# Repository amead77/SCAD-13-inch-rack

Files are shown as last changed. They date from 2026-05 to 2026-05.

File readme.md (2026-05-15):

Most of this readme was wrote by copilot, because I am a forklift operator, not a novelist. But I did write most of the code (except variable tray, which copilot fixed for me then refactored) and the spec.

If you like the design, you're welcome to buy me a coffee:

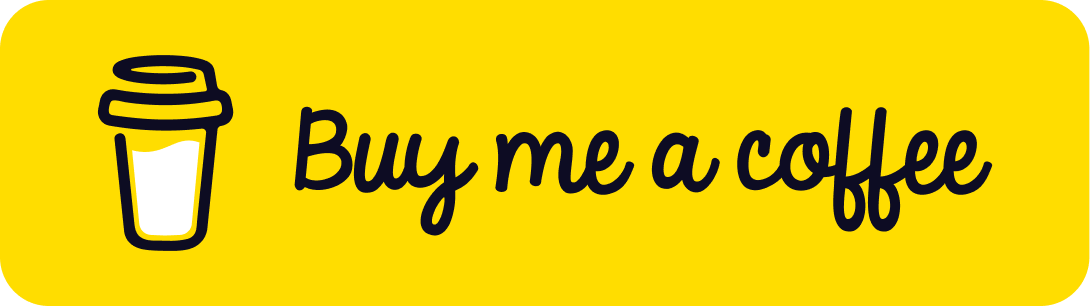
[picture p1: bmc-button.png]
Buy Me a Coffee


# 330mm / 13-Inch Rack System (OpenSCAD)

A parametric, 3D-printable rack system designed for larger-format printers such as the Creality K2 Plus, Prusa XL, etc. The rack is 330mm wide — measured from the left edge of the left post to the right edge of the right post (single-post configuration).

Assembly overview

Rear view of assembly

Assembly with 8 legs

---

## Design Goals

- **Rear-slide tray support** — trays slide into a slot in the rear post rather than bolting front and rear. This means trays can be removed without dismantling the rack.
- **Fully parametric** — all dimensions, hole counts, heights and clearances are driven by variables. Use the OpenSCAD Customizer to configure parts without editing code.
- **Modular** — mix single/double-wide posts, variable-height trays and panels, and optional joiners.

---

## Parts

### Posts

Posts are the vertical rails of the rack. They are generated in configurable U heights and can be single or double wide. A slide channel can be added to the left side, right side, both sides, or neither. 

Post

### Trays

Trays are available in fixed sizes (1U, 2U) or a fully variable size. The variable tray accepts a `tray_back_panel` flag to add a rear panel, turning it into a drawer. Trays slide into the post's rear slot for easy removal. Trays also don't need to be full length, defining 0.25 will make a quarter depth tray (y axis)

Variable tray

Part Tray

### Panels (Blanking Panels)

Flat front panels for blanking unused rack slots. Available in ½U, 1U, 2U, and variable sizes.

Half-U panel

2U panel

### Footer / Header

Optional pieces added to the top and bottom of posts. They provide an attachment point for the joiners.

### Joiners (Base / Top)

Optional horizontal joiners that connect the front posts to the rear posts via the footer/header. 
You can have more than just 4 posts. The joiners can have 2+ supports, by increasing the number and printing more posts, you can have greater supports

Top joiner

---

## Custom Trays

The file `rack custom tray 01.scad` provides an example of a custom tray — including IO cutouts (e.g. Raspberry Pi 5 USB/Ethernet ports), standoffs with heat-set inserts, and embossed logos. Use this as a starting point for your own designs.

---

## Usage

1. Open `rack parts.scad` in OpenSCAD (use the nightlys, the offical releases are mega old).
2. Open the **Customizer** panel (Window → Customizer).
3. Select the part you want from the `part` dropdown:
   - `assembly` — preview all parts together
   - `post` — a single post
   - `base joiner` / `top joiner` — horizontal joiners
   - `1U tray` / `2U tray` / `variable tray` — trays
   - `halfUpanel` / `1U panel` / `2U panel` / `variable panel` — blanking panels
4. Adjust the parameters to suit your needs.
5. Render (F6) and export to STL or 3MF

### Key Parameters

| Parameter | Description |
|---|---|
| `post_u_height` | Height of the post in U units |
| `post_doublewide` | `0` = single wide, `1` = double wide |
| `slide_side` | `0` none, `1` left, `2` right, `3` both |
| `front_panel_height` | Panel/tray height in U (can be fractional, e.g. `1.5`) |
| `front_panel_hole_count` | Mounting holes per side (2, 3, 4, or 6) |
| `tray_side_height` | Tray side wall height in hole spacings |
| `tray_back_panel` | `0` = open tray, `1` = drawer with rear panel |
| `footer_include` / `header_include` | Include footer/header attachment pieces |

### Hardware

The design is based on **M6 screws** with **M6 hex nuts** (10mm across-flats, 5mm thick). Adjust `hole_clearance`, `hole_d`, `nut_diameter`, and `nut_thickness` in `rack defines.scad` if you want to use different fasteners.

---

## File Structure

| File | Purpose |
|---|---|
| `rack parts.scad` | Main entry point — select and configure parts here |
| `rack defines.scad` | All default dimensions and constants |
| `rack posts.scad` | Post geometry |
| `rack tray.scad` | Tray and panel geometry |
| `rack custom tray 01.scad` | Example custom tray (Raspberry Pi 5) |
| `rack *.3mf` | Pre-sliced print files for reference |

---

## Requirements

- [OpenSCAD](https://openscad.org/) the releases are ancient, use the nightlies instead.
- A printer with at least 330mm on one axis (e.g. Creality K2 Plus, Prusa XL)

---

## License

This project is licensed under the **Creative Commons - Attribution (CC BY)** for all the parts and **Creative Commons - Attribution - Non-Commercial (CC BY-NC)** for the specifications.

In simpler terms, you can remix and do whatever you want with making parts or modifying the parts, including selling. But the design spec, that is 330mm dimension and guide slots, is the same terms but non-commercial use. This is specifically aimed at companies making 13"/330mm racks using my design, not someone who makes some mods or addons and sells them.

&copy; 2026 Adam Mead

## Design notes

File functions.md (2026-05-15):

# 330mm Rack — Module Reference & Definitions

---

## Definitions (`rack defines.scad`)

These are the global defaults. Many can be overridden in `rack parts.scad` or passed directly as function parameters.

### Rack geometry

| Variable | Default | Notes |
|---|---|---|
| `rack_width` | `330` | Overall rack width in mm. Left edge of left post to right edge of right post (single-width posts). Best left alone. |
| `post_width` | `15.875` | Standard rack post width in mm. |
| `u_height` | `44.5` | Height of one rack unit (1U) in mm. |
| `v_post_height` | `3` | Default post height in U units. Used when `post_height` isn't passed to `rail_1u_holes()`. |
| `post_height` | `u_height × v_post_height` | Computed total post height in mm. Read-only — set `v_post_height` instead. |

### Hole / nut geometry

| Variable | Default | Notes |
|---|---|---|
| `hole_clearance` | `0.3` | Extra clearance added to all hole diameters. |
| `hole_d` | `6.0 + hole_clearance` | Final M6 screw hole diameter. |
| `hole_offset_z` | `12.7` | Vertical distance from the bottom of a 1U segment to the first hole centre. Half this value is used between U sections. |
| `hole_spacing` | `15.875` | Vertical spacing between holes within a 1U segment (standard rack pitch). |
| `nut_diameter` | `10.0 + hole_clearance` | M6 hex nut across-flats diameter with clearance. |
| `nut_diameter_point` | computed | M6 hex nut point-to-point diameter (used for hex cutout). |
| `nut_thickness` | `6.0 + hole_clearance` | Depth of the nut trap. Increase if your screws are short. |

### Post slide rails (for tray sliding)

| Variable | Default | Notes |
|---|---|---|
| `post_slide_width` | `3.0` | Width of the slide rail that protrudes from the post side. |
| `post_slide_cutout` | `3.2` | Height of the slot cut into the slide rail for tray tabs. |

### Alignment cones (for stacking / joining posts)

| Variable | Default | Notes |
|---|---|---|
| `post_cone_base_diameter` | `10.0` | Diameter at the base of the alignment cone. |
| `post_cone_top_diameter` | `4.0` | Diameter at the tip of the alignment cone. |
| `post_cone_height` | `2.0` | Height of the cone. |
| `post_top_cone_clearance` | `0.1` | Amount the male cone is undersized for a slip fit. |
| `post_cones` | `1` | `1` = include cones by default. `0` = omit. |

### Footer / header (post end blocks)

| Variable | Default | Notes |
|---|---|---|
| `footer_height` | `12.7` | Height of the footer block at the bottom of a post. Sized so a 0.5U panel fits between post bottom and joiner beam. |
| `footer_include` | `1` | `1` = generate footer by default. `0` = omit. |
| `header_height` | `12.7` | Height of the header block at the top of a post. Same logic as footer. |
| `header_include` | `1` | `1` = generate header by default. `0` = omit. |

### Joiner beams

| Variable | Default | Notes |
|---|---|---|
| `footer_base_beam_thickness` | `5.0` | Thickness of the bottom joiner beam. Can be overridden directly in the `base_joiner()` call. |
| `header_top_beam_thickness` | `10.0` | Thickness of the top joiner beam. Can be overridden directly in the `base_joiner()` call. |

### Front panels

| Variable | Default | Notes |
|---|---|---|
| `front_panel_thickness` | `3.0` | Panel face thickness. Too thick and screws won't reach. |
| `front_panel_undersizing` | `0.1` | How much to trim the panel perimeter on each edge for a better fit. |
| `front_panel_edge_radius` | `2.0` | Corner rounding radius. `0` for sharp corners. |
| `front_panel_hole_count` | `2` | Default mounting holes per side (`2`, `3`, `4`, or `6`). |

### Trays

| Variable | Default | Notes |
|---|---|---|
| `tray_thickness` | `5.0` | Thickness of the tray floor. |
| `tray_post_clearance` | `0.5` | Gap between the tray side and the post, applied to both sides. |
| `tray_side_thickness` | `2.0` | Wall thickness of the tray sides. |
| `tray_slide_thickness` | `post_slide_cutout - hole_clearance` | Thickness of the tab that slots into the post rail. Computed; do not set manually. |
| `tray_to_panel_support_distance` | `30.0` | How far back from the front panel the side-wall gussets reach. |

---

## Public Modules

### `rack posts.scad`

---

#### `rail_1u_holes()` — Complete rack post

Generates a full-height rack post with M6 holes, nut traps, optional slide rails, footer/header blocks, and alignment cones.

```scad
rail_1u_holes(
    slide_side,                          // required: 0=none, 1=left, 2=right, 3=both
    doublewide      = 0,                 // 0=single post width, 1=double
    post_height     = v_post_height,     // height in U units
    v_post_cones    = post_cones,        // 1=add alignment cones
    include_footer  = footer_include,    // 1=add footer block
    include_header  = header_include     // 1=add header block
)
```

Examples:
```scad
rail_1u_holes(slide_side=1, doublewide=0, post_height=6, v_post_cones=1);
rail_1u_holes(slide_side=3, doublewide=1, post_height=4);
```

---

#### `base_joiner()` — Front-to-rear joiner (bottom or top)

Horizontal beam that spans from front post to rear post, attaching to the footer or header blocks. Can generate extra intermediate support blocks at equal spacing.

```scad
base_joiner(
    doublewide      = 0,    // 0=single, 1=double
    bottom          = 1,    // 1=base/footer joiner, 0=top/header joiner
    supports        = 2,    // min 2 (front + rear); >2 adds equally-spaced intermediate blocks
    beam_thickness  = 5.0   // beam thickness in mm (overrides the define default)
)
```

Examples:
```scad
base_joiner();                                                      // base joiner, single wide, 2 supports
base_joiner(bottom=0, beam_thickness=10);                           // top joiner
base_joiner(supports=4);                                            // base joiner with 2 extra intermediate supports
base_joiner(doublewide=1, supports=3, beam_thickness=6);
```

---

### `rack tray.scad`

---

#### `blank_1U_front_panel()` — 1U blanking panel

Full-width 1U front panel with optional corner rounding and configurable hole count.

```scad
blank_1U_front_panel(holes = front_panel_hole_count)
// holes: 2, 3, 4, or 6 per side
```

Examples:
```scad
blank_1U_front_panel();
blank_1U_front_panel(holes=3);
```

---

#### `blank_2U_front_panel()` — 2U blanking panel

Full-width 2U front panel.

```scad
blank_2U_front_panel(holes = 4)
// holes: 2, 4, or 6 per side
```

---

#### `blank_05U_front_panel()` — 0.5U blanking panel

Fixed half-U panel used at the top and bottom of the rack to bridge the gap between post ends and joiners. No parameters.

```scad
blank_05U_front_panel();
```

---

#### `blank_variable_front_panel()` — Variable-height blanking panel

Front panel at any fractional U height, with optional embossed or engraved SVG/STL artwork.

```scad
blank_variable_front_panel(
    u_size          = 1,                    // panel height in U (can be fractional)
    holes           = front_panel_hole_count,
    import_file     = "",                   // path to SVG or STL file
    import_type     = "none",               // "svg", "stl", or "none"
    import_width    = 0,                    // 0 = auto (50% of panel width)
    import_height   = 0,                    // 0 = auto (50% of panel height)
    import_depth    = 0.8,                  // emboss height / engrave depth in mm
    import_offset_x = 0,                    // X offset from centre
    import_offset_z = 0,                    // Z offset from centre
    import_mode     = "emboss"              // "emboss" (raised) or "engrave" (cut in)
)
```

Examples:
```scad
blank_variable_front_panel(u_size=1.5, holes=2);
blank_variable_front_panel(u_size=2, holes=4, import_file="logo.svg", import_type="svg", import_mode="engrave");
```

---

#### `blank_1U_tray()` — 1U tray

1U tray shell with front panel and side slide tabs. Use as a starting point for custom 1U trays.

```scad
blank_1U_tray(
    side_count  = 3,                    // slide tabs per side (1–3)
    edge_radius = 2,                    // front panel corner radius
    holes       = front_panel_hole_count
)
```

---

#### `blank_2U_tray()` — 2U tray

2U tray shell with front panel and side slide tabs.

```scad
blank_2U_tray(
    side_count  = 3,    // slide tabs per side (1–6)
    edge_radius = 2,
    holes       = 4
)
```

---

#### `blank_variable_tray()` — Variable-size tray *(preferred)*

The main tray module. Supports any fractional U size for both the front panel and the tray body independently, variable depth, optional rear wall (drawer mode), front gussets, and emboss/engrave graphics. Preferred over `blank_1U_tray` / `blank_2U_tray` for new designs.

```scad
blank_variable_tray(
    panel_u_size            = 1,                    // front panel height in U
    tray_u_size             = panel_u_size,         // side/base height in U (defaults to panel_u_size)
    tray_depth_scale        = 1,                    // depth as fraction of rack depth (1 = full, 0.5 = half)
    holes                   = front_panel_hole_count,
    import_file             = "",
    import_type             = "none",               // "svg", "stl", or "none"
    import_width            = 0,
    import_height           = 0,
    import_depth            = 0.8,
    import_offset_x         = 0,
    import_offset_z         = 0,
    import_mode             = "emboss",             // "emboss" or "engrave"
    side_support            = 1,                    // 1=add front gussets where panel is taller than side
    side_support_back       = 40,                   // how far back (mm) the gusset reaches
    side_support_thickness  = tray_side_thickness,
    back_panel              = 0,                    // 1=add rear wall (drawer mode)
    back_panel_thickness    = tray_side_thickness
)
```

Examples:
```scad
blank_variable_tray(panel_u_size=1, tray_u_size=0.75, holes=2);
blank_variable_tray(panel_u_size=1, tray_u_size=0.75, tray_depth_scale=0.5, back_panel=1);
blank_variable_tray(panel_u_size=2, tray_u_size=1.5, holes=4, import_file="logo.svg", import_type="svg", import_mode="emboss");
```

---

#### `post_base_join_panel()` — Post-to-joiner connector panel

Small flat panel sized to one or two post footprints. Provides two M6 holes per post footprint to physically fasten a post to a base joiner at an intermediate support position.

```scad
post_base_join_panel(
    doublewide  = 0,                        // 0=one post width, 1=two post widths
    thickness   = front_panel_thickness     // panel thickness in mm
)
```

Examples:
```scad
post_base_join_panel();
post_base_join_panel(doublewide=1, thickness=4);
```

---

### `rack custom tray 01.scad`

---

#### `standoff_heat_insert()` — Cylindrical standoff with heat-set insert bore

Utility module for placing a single PCB standoff with a heat-set insert hole at the top.

```scad
standoff_heat_insert(
    x, y, z,            // centre position of the standoff base
    h            = 6,   // standoff height
    d            = 7.0, // outer diameter
    insert_d     = 3.8, // bore diameter for heat-set insert
    insert_depth = 4.5  // depth of the bore from the top
)
```

Example:
```scad
standoff_heat_insert(x=20, y=15, z=5, h=6, d=7.0, insert_d=3.8, insert_depth=4.5);
```

---

#### `rpi5_standoffs_left()` — Raspberry Pi 5 standoff set

Places four `standoff_heat_insert()` standoffs at the standard Raspberry Pi 5 mounting hole pattern (58 × 49 mm).

```scad
rpi5_standoffs_left(
    mount_origin_x  = post_width + 14, // X of the bottom-left hole
    mount_origin_y  = front_panel_thickness + 9, // Y of the bottom-left hole
    hole_dx         = 58,              // hole spacing in X
    hole_dy         = 49,              // hole spacing in Y
    standoff_h      = 6,
    standoff_d      = 7.0,
    insert_d        = 3.8,
    insert_depth    = 4.5
)
```

Example:
```scad
rpi5_standoffs_left(mount_origin_x=30, mount_origin_y=23, hole_dx=49, hole_dy=58);
```

---

#### `custom_tray_01()` — Example Raspberry Pi 5 tray

Pre-built 1U tray for a Raspberry Pi 5 with active cooler. Includes an embossed Pi logo, USB/Ethernet IO cutout, and four M3 heat-set standoffs at the Pi 5 hole pattern. Also imports the Pi 5 STL for fitment checking. No parameters — edit the constants inside the module to adjust positioning.

```scad
custom_tray_01();
```

---

## Assembly (`rack parts.scad`)

The `part` variable at the top of this file selects what to render. Set it in the OpenSCAD Customiser or edit directly.

| `part` value | What it renders |
|---|---|
| `"assembly"` | All parts together for a preview of the complete rack |
| `"post"` | A single post at the configured height/width |
| `"base joiner"` | The bottom front-to-rear joiner |
| `"top joiner"` | The top front-to-rear joiner |
| `"1U tray"` | Blank 1U tray |
| `"2U tray"` | Blank 2U tray |
| `"variable tray"` | Variable-size tray |
| `"halfUpanel"` | 0.5U blanking panel |
| `"1U panel"` | 1U blanking panel |
| `"2U panel"` | 2U blanking panel |
| `"variable panel"` | Variable-height blanking panel |
| `"post joins"` | Post-to-joiner connector panels |

### Key assembly parameters

| Variable | Notes |
|---|---|
| `post_u_height` | Post height in U units |
| `post_doublewide` | `0` = single, `1` = double wide |
| `slide_side` | `0`=none, `1`=left, `2`=right, `3`=both |
| `cones` | `1` = alignment cones on posts and joiners |
| `base_support_count` | Number of front-to-rear joiner support positions (min 2). `>2` adds evenly-spaced intermediate posts and joiner blocks. |
| `footer_include` / `header_include` | `1` = include footer/header blocks |
| `base_join` / `top_join` | `1` = include bottom/top joiners in assembly |
| `base_panel` / `top_panel` | `1` = include 0.5U bridging panels at bottom/top |
| `footer_base_beam_thickness` | Beam thickness for the bottom joiner |
| `header_top_beam_thickness` | Beam thickness for the top joiner |

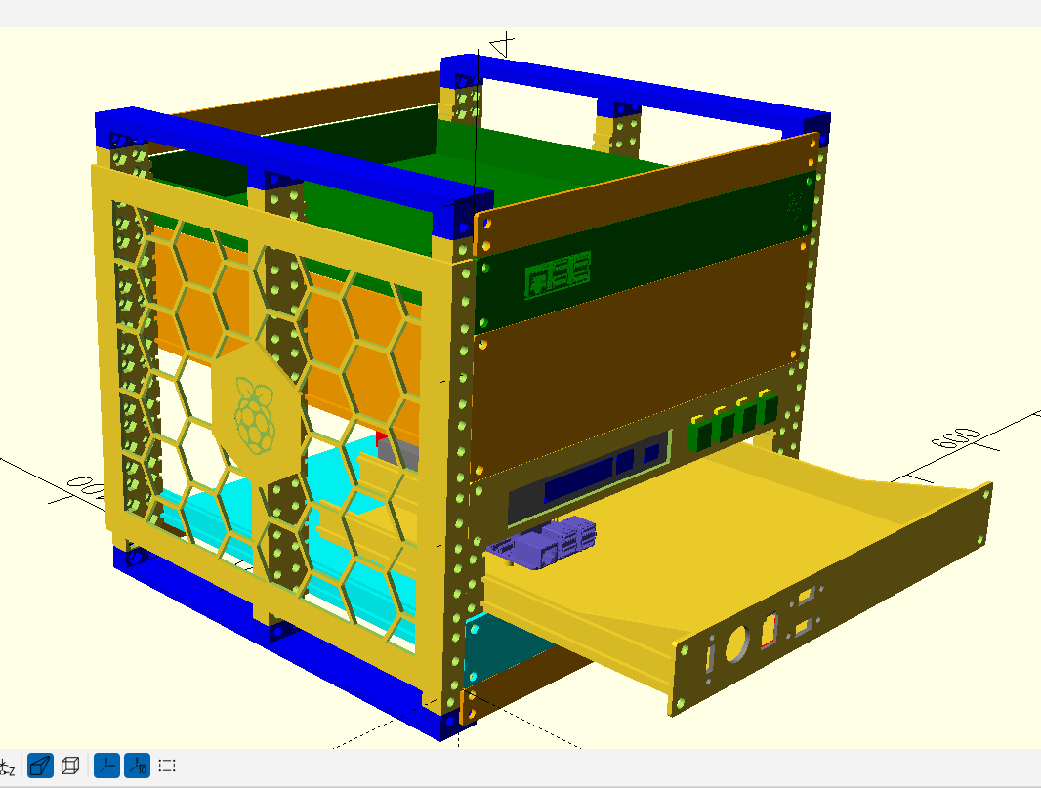
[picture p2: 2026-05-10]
overview-with-side-panel.png

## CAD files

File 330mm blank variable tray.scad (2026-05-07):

// 330mm blank variable tray.scad
// Variable-height front panel and tray modules.
// All rack dimensions are explicit parameters — no external defines file required.
// Default values match the 330mm rack standard (front_panel_thickness=3, rack_width=330, etc.).
//
// Public modules:
//   blank_variable_front_panel(...)  — variable-height blanking front panel
//   blank_variable_tray(...)         — variable-height tray with front panel and side slides
//
// All parameters have sensible defaults so the modules work out of the box for a standard
// 330mm rack, but every dimension can be overridden on the call.


// =============================================================================
// Internal helpers
// =============================================================================

// variable_holes_per_u(holes)
// Converts a total holes-per-side value into a per-U-segment count (1, 2, or 3).


/*
// next 2 lines used only by my 'on save' script. can be ignored otherwise.
// AUTO-V
version = "v0.1-2026/05/07r07";
*/

function variable_holes_per_u(holes) = (holes >= 6) ? 3 : ((holes >= 4) ? 2 : holes);


// variable_front_panel_hole_at(x_pos, z_pos, post_width, hole_d)
// Subtracts a single screw hole through the front panel at the given X and Z position.
module variable_front_panel_hole_at(
    x_pos,
    z_pos,
    post_width = 15.875,
    hole_d     = 6.3
) {
    translate([x_pos, post_width / 2, z_pos]) {
        rotate([90, 0, 0]) {
            cylinder(d = hole_d, h = post_width, center = true, $fn = 32);
        }
    }
}


// variable_front_panel_holes(panel_height, holes, u_height, hole_offset_z, hole_spacing, post_width, rack_width, hole_d)
// Subtracts the correct pattern of screw holes across a variable-height front panel.
// holes: mounting holes per side (2, 3, 4, or 6).
module variable_front_panel_holes(
    panel_height,
    holes        = 2,
    u_height     = 44.5,
    hole_offset_z = 12.7,
    hole_spacing = 15.875,
    post_width   = 15.875,
    rack_width   = 330,
    hole_d       = 6.3
) {
    holes_per_u    = variable_holes_per_u(holes);
    max_u_segments = ceil(panel_height / u_height);

    for (u_seg = [0 : max_u_segments - 1]) {
        if (holes_per_u >= 1) {
            z1 = (u_seg * u_height) + (hole_offset_z / 2);
            if (z1 <= panel_height - (hole_offset_z / 2) + 0.001) {
                variable_front_panel_hole_at(post_width / 2,             z1, post_width, hole_d);
                variable_front_panel_hole_at(rack_width - post_width / 2, z1, post_width, hole_d);
            }
        }
        if (holes_per_u >= 2) {
            z2 = (u_seg * u_height) + (hole_offset_z / 2) + (hole_spacing * 2);
            if (z2 <= panel_height - (hole_offset_z / 2) + 0.001) {
                variable_front_panel_hole_at(post_width / 2,             z2, post_width, hole_d);
                variable_front_panel_hole_at(rack_width - post_width / 2, z2, post_width, hole_d);
            }
        }
        if (holes_per_u >= 3) {
            z3 = (u_seg * u_height) + (hole_offset_z / 2) + hole_spacing;
            if (z3 <= panel_height - (hole_offset_z / 2) + 0.001) {
                variable_front_panel_hole_at(post_width / 2,             z3, post_width, hole_d);
                variable_front_panel_hole_at(rack_width - post_width / 2, z3, post_width, hole_d);
            }
        }
    }
}


// variable_front_panel_body(panel_height, front_panel_thickness, rack_width, front_panel_undersizing, front_panel_edge_radius)
// Generates the solid panel body at the given height in mm, with optional edge rounding.
module variable_front_panel_body(
    panel_height,
    front_panel_thickness  = 3.0,
    rack_width             = 330,
    front_panel_undersizing = 0.1,
    front_panel_edge_radius = 2.0
) {
    if (front_panel_edge_radius > 0) {
        translate([
            front_panel_undersizing + front_panel_edge_radius,
            0,
            front_panel_undersizing + front_panel_edge_radius
        ]) {
            minkowski() {
                cube([
                    rack_width   - (front_panel_undersizing * 2) - (front_panel_edge_radius * 2),
                    front_panel_thickness,
                    panel_height - (front_panel_undersizing * 2) - (front_panel_edge_radius * 2)
                ]);
                rotate([90, 0, 0]) {
                    cylinder(r = front_panel_edge_radius, h = 0.01, center = true, $fn = 32);
                }
            }
        }
    } else {
        translate([front_panel_undersizing, 0, front_panel_undersizing]) {
            cube([
                rack_width   - (front_panel_undersizing * 2),
                front_panel_thickness,
                panel_height - (front_panel_undersizing * 2)
            ]);
        }
    }
}


// variable_front_panel_face_import(panel_height, import_file, import_type, import_width, import_height, import_depth, import_offset_x, import_offset_z, import_mode, rack_width, front_panel_undersizing)
// Embosses or engraves an SVG or STL/3MF onto the front panel face.
// import_type: "svg", "stl", or "none". import_mode: "emboss" (raised) or "engrave" (cut in).
// Called by blank_variable_front_panel(); not normally used directly.
module variable_front_panel_face_import(
    panel_height,
    import_file             = "",
    import_type             = "none",
    import_width            = 0,
    import_height           = 0,
    import_depth            = 0.8,
    import_offset_x         = 0,
    import_offset_z         = 0,
    import_mode             = "emboss",
    rack_width              = 330,
    front_panel_undersizing = 0.1
) {
    if ((import_type != "none") && (import_file != "")) {
        panel_inner_width  = rack_width   - (front_panel_undersizing * 2);
        panel_inner_height = panel_height - (front_panel_undersizing * 2);

        target_width  = (import_width  > 0) ? import_width  : panel_inner_width  * 0.5;
        target_height = (import_height > 0) ? import_height : panel_inner_height * 0.5;
        target_depth  = (import_depth  > 0) ? import_depth  : 0.8;

        x_pos = front_panel_undersizing + (panel_inner_width  / 2) + import_offset_x;
        z_pos = front_panel_undersizing + (panel_inner_height / 2) + import_offset_z;

        if (import_type == "svg") {
            if (import_mode == "engrave") {
                // Use a tiny overlap so CSG subtraction reliably intersects the panel volume.
                translate([x_pos, target_depth + 0.01, z_pos]) {
                    rotate([90, 0, 0]) {
                        linear_extrude(height = target_depth + 0.02) {
                            resize([target_width, target_height], auto = true) {
                                import(file = import_file, center = true);
                            }
                        }
                    }
                }
            } else {
                // Emboss out from the front face (y = -depth to 0).
                translate([x_pos, 0, z_pos]) {
                    rotate([90, 0, 0]) {
                        linear_extrude(height = target_depth) {
                            resize([target_width, target_height], auto = true) {
                                import(file = import_file, center = true);
                            }
                        }
                    }
                }
            }
        } else {
            // STL/3MF: assumes mesh uses X=width, Z=height, Y=depth.
            y_pos = (import_mode == "engrave") ? (target_depth / 2) : -(target_depth / 2);
            translate([x_pos, y_pos, z_pos]) {
                resize([target_width, target_depth, target_height], auto = false) {
                    import(file = import_file, center = true);
                }
            }
        }
    }
}
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

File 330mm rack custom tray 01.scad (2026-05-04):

include <330mm rack tray.scad>;

/*
// next 2 lines used only by my 'on save' script. can be ignored otherwise.
// AUTO-V
version = "v0.1-2026/05/04r12";
*/


// rpi5_io_cutout_left(cutout_x, cutout_z, cutout_w, cutout_h, clearance)
// Internal helper — subtracts a rectangular IO port cutout from the front panel, sized for the Raspberry Pi 5 USB/Ethernet side.
// cutout_x: X offset from left edge. cutout_z: Z offset from bottom. cutout_w/cutout_h: opening size. clearance: extra clearance on all sides.
// Subtract this from a tray/panel body inside a difference() block.
module rpi5_io_cutout_left(
    cutout_x = post_width + 8,
    cutout_z = 10,
    cutout_w = 56,
    cutout_h = 18,
    clearance = 0.6
) {
    // Cut through the full front panel thickness with a little overlap for reliable subtraction.
    translate([cutout_x - clearance, -0.5, cutout_z - clearance]) {
        cube([cutout_w + (clearance * 2), front_panel_thickness + 1.0, cutout_h + (clearance * 2)]);
    }
}


// standoff_heat_insert(x, y, z, h, d, insert_d, insert_depth)
// Utility — generates a cylindrical standoff with a heat-set insert bore at the top.
// x/y/z: centre position. h: standoff height. d: outer diameter.
// insert_d: bore diameter for the heat-set insert. insert_depth: depth of the bore.
// e.g. standoff_heat_insert(x=20, y=15, z=5, h=6, d=7.0, insert_d=3.8, insert_depth=4.5);
module standoff_heat_insert(
    x,
    y,
    z,
    h = 6,
    d = 7.0,
    insert_d = 3.8,
    insert_depth = 4.5
) {
    difference() {
        translate([x, y, z]) {
            cylinder(h = h, d = d, center = false, $fn = 48);
        }
        // Bore for heat-set insert, entering from standoff top.
        translate([x, y, z + h - insert_depth]) {
            cylinder(h = insert_depth + 0.2, d = insert_d, center = false, $fn = 32);
        }
    }
}


// rpi5_standoffs_left(mount_origin_x, mount_origin_y, hole_dx, hole_dy, standoff_h, standoff_d, insert_d, insert_depth)
// Utility — places four standoffs in the standard Raspberry Pi 5 mounting hole pattern (58 x 49 mm).
// mount_origin_x/y: position of the bottom-left mounting hole. hole_dx/hole_dy: hole spacing in X and Y.
// Standoff parameters are passed through to standoff_heat_insert().
// e.g. rpi5_standoffs_left(mount_origin_x=30, mount_origin_y=23, hole_dx=49, hole_dy=58);
module rpi5_standoffs_left(
    mount_origin_x = post_width + 14,
    mount_origin_y = front_panel_thickness + 9,
    hole_dx = 58,
    hole_dy = 49,
    standoff_h = 6,
    standoff_d = 7.0,
    insert_d = 3.8,
    insert_depth = 4.5
) {
    standoff_z = front_panel_undersizing + tray_thickness;

    standoff_heat_insert(mount_origin_x,           mount_origin_y,           standoff_z, standoff_h, standoff_d, insert_d, insert_depth);
    standoff_heat_insert(mount_origin_x + hole_dx, mount_origin_y,           standoff_z, standoff_h, standoff_d, insert_d, insert_depth);
    standoff_heat_insert(mount_origin_x,           mount_origin_y + hole_dy, standoff_z, standoff_h, standoff_d, insert_d, insert_depth);
    standoff_heat_insert(mount_origin_x + hole_dx, mount_origin_y + hole_dy, standoff_z, standoff_h, standoff_d, insert_d, insert_depth);
}


// custom_tray_01()
// Public — example custom tray for a Raspberry Pi 5 with active cooler.
// Builds a 1U panel / 0.75U tray with: Raspberry Pi logo embossed on the front panel,
// USB/Ethernet IO cutout on the left side, four M3 heat-set standoffs at the Pi 5 hole pattern,
// and an imported Pi 5 model for fitment checking.
// No parameters. Adjust the constants inside to reposition or resize.
// e.g. custom_tray_01();
module custom_tray_01() {
    // Tray + panel with Pi 5 left-side I/O cutout on the USB/Ethernet side.
    difference() {
        blank_variable_tray(
            panel_u_size = 1,
            tray_u_size = 0.75,
            holes = 2,
            import_file = "raspberry-pi.svg",
            import_type = "svg",
            import_width = 16,
            import_height = 20,
            import_depth = 0.2,
            import_offset_x = 140,
            import_offset_z = 0,
            import_mode = "emboss",
            side_support = 1,
            back_panel = 1
        );

        rpi5_io_cutout_left(
            cutout_x = post_width + 26,
            cutout_z = 8+tray_thickness,
            cutout_w = 56,
            cutout_h = 18,
            clearance = 0.6
        );
    }

    // Pi 5 mounting standoffs (58x49 hole pattern) for heat-set inserts.
    rpi5_standoffs_left(
        mount_origin_x = post_width + 29.5,
        mount_origin_y = front_panel_thickness + 23,
        hole_dx = 49,
        hole_dy = 58,
        standoff_h = 6,
        standoff_d = 7.0,
        insert_d = 3.8,
        insert_depth = 4.5
    );

    //import raspberry pi 5 model to test fitment
    translate([post_width + 14, front_panel_thickness + 9, front_panel_undersizing + tray_thickness]) {
        translate([40, 33, 7]) { // move the model so the mounting holes are at the origin, for easier positioning
            rotate([90, 0, 270]) {
                color("blue") {
                    import("raspberry_pi_5_with_active_cooler.stl", convexity = 10);
                }
             }
        }   
    }
}

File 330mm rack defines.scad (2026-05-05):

/*

DEPRECIATED.

use for reference. The default values in the functions are now set to these, and can be overridden when calling the functions.

*/


//some of these are overrode by calling the functions with different parameters, these are defaults if not specified.
//in the main assembly/"rack parts" files, some of these get overridden by assignments there. this is deliberate as below is defaults if that other file isn't found.

hole_clearance = 0.3; //mm clearance around the 'oles
rack_width = 330; //maybe leave this alone
post_width = 15.875; // standard post width for rack.
u_height = 44.5; // 1U in mm for post
v_post_height = 3; //this is in standard 1U units, not mm.
post_height = u_height * v_post_height; // total height of posts, in mm.
hole_d = 6.0 + hole_clearance; //screw holes dia
hole_offset_x = post_width/2 + hole_d/2; //should be central
hole_offset_z = 12.7; // standard spacing. half this for between 1U sections.
hole_spacing = 15.875; //rail hole spacing

nut_diameter = 10.0 + hole_clearance; //10mm for m6 THIS IS ACROSS THE FLATS, not point to point.
nut_diameter_point = nut_diameter / cos(30); // diameter of the hexagon nut point to point
nut_thickness = 6.0 + hole_clearance; //5mm for m6 - CONSIDER YOUR SCREW DEPTH AND PANEL THICKNESS HERE (my screws didn't reach far enough, so increased depth to counter)

post_slide_width = 3.0; //this is the width of the cutout for the trays to slide into.
post_slide_cutout = 3.2; //this is the height of the cutout for the trays to slide into


post_cone_base_diameter = 10.0; // base diameter of the alignment cone on top of posts
post_cone_top_diameter = 4.0; // tip diameter of the alignment cone
post_cone_height = 2.0; // height of the alignment cone
post_top_cone_clearance = 0.1; // this is how much smaller the top cone is than the bottom cone, for clearance when joining.
post_cones = 1; //1 = add cones to top and difference from the bottom of the post. This is for joining.

front_panel_thickness = 3.0; // how thick the front panel is, go too thick and your screws might not reach.
front_panel_undersizing = 0.1; // this is how many mm to undersize the front panel, for better fitting. it affects x and z and is applied to both edges, not just one
front_panel_edge_radius = 2.0; // this is the radius of the rounded edges on the front panel. Set to 0 for square edges.
front_panel_hole_count = 2; //this is per side. 2 or 3 or 4 or 6. for certain panels and hole spacing just play with this.
tray_thickness = 5.0; // this is not affected by post_slide_cutout, as it sits inside
tray_post_clearance = 0.5; //clearance between trays and posts. added to BOTH sides.
tray_side_thickness = 2.0; // thickness of the side wall of the tray.
tray_slide_thickness = post_slide_cutout - hole_clearance; // thickness of the tray slide tab that fits into the post slot.
tray_to_panel_support_distance = 30.0; //this is the distance the front panel support reaches back to the side slides.

footer_height = 12.7; //this and the header height are the same, the distance is so a 0.5U panel joins them
footer_width = 1; //this is in POST WIDTHS, not mm.
footer_include = 1; // set to 0 to not include the footer, 1 to include it. The footer is a small piece at the bottom of the rack
header_height = 12.7; // same as footer_height, distance is so a 0.5U panel joins them.
header_width = 1; //this is in POST WIDTHS, not mm.
header_include = 1; // set to 0 to not include the header, 1 to include it. The header is a small piece at the top of the rack

// the next 2 lines are used for creating joining beams for the front and rear of the rack, connecting the posts.
// they are the same connector apart as the footer/header.
// deprecated. These are now specified when calling the function.
header_top_beam_thickness = 10.0; // the top beam for connecting 2 posts/rails together, front to rear.
footer_base_beam_thickness = 5.0; // the base beam for connecting 2 posts/rails together, front to rear.
beam_thickness = 4; //this is used internally, do not adjust.

/*
// next 2 lines used only by my 'on save' script. can be ignored otherwise.
// AUTO-V
version = "v0.1-2026/05/05r01";
*/

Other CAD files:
330mm rack feet.scad
330mm rack parts.scad
330mm rack posts.scad
330mm rack side panel.scad
330mm rack tray.scad
blank variable tray.scad
dell optiplex 3080.scad
honeycomb.scad
intel dg45fg.scad
keystone panel.scad
rack custom tray 01.scad
rack parts.scad
rack posts.scad
rack side panel.scad
rack tray.scad
rpi5.scad
ugreen um106x.scad

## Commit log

2026-05-03 1u sides
    [330mm rack parts.scad]
2026-05-03 rails and blank tray working
    [330mm rack parts.scad]
2026-05-03 adding doublewide
    [330mm rack parts.scad]
2026-05-03 begin feet design and post split to individual files
    [330mm rack defines.scad, 330mm rack feet.scad, 330mm rack parts.scad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]
2026-05-03 fixing things after moving
    [330mm rack defines.scad, 330mm rack parts.scad, 330mm rack posts.scad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]
2026-05-03 add back panel/drawer mode
    [330mm rack custom tray 01.scad, 330mm rack defines.scad, 330mm rack parts.scad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]
2026-05-04 tidy up, improve customiser funcs
    [330mm rack parts.scad]
2026-05-04 readme, comments
    [330mm rack custom tray 01.scad, 330mm rack defines.scad, 330mm rack parts.scad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]
2026-05-05 split variable panel and tray, detach from fixed defines
    [330mm blank variable tray.scad, 330mm rack defines.scad, 330mm rack posts.scad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]
2026-05-05 further defines detachments
    [330mm rack posts.scad, ugreen um106x.scad]
2026-05-05 getting the switch tray working
    [330mm blank variable tray.scad, 330mm rack defines.scad, ugreen um106x.scad]
2026-05-07 adjust variable tray to have differing height rear panel (if needed)
    [330mm blank variable tray.scad, keystone panel.scad, ugreen um106x.scad]
2026-05-10 side panel
    [330mm rack parts.scad, 330mm rack side panel.scad, honeycomb.scad]
2026-05-10 side panel and assembly view
    [330mm rack parts.scad, 330mm rack side panel.scad]
2026-05-10 assembly view text and update
    [330mm rack parts.scad, 330mm rack side panel.scad, ugreen um106x.scad]
2026-05-15 screw positions
    [intel dg45fg.scad]
2026-05-15 variable size fixes
    [blank variable tray.scad, dell optiplex 3080.scad, rack parts.scad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]
